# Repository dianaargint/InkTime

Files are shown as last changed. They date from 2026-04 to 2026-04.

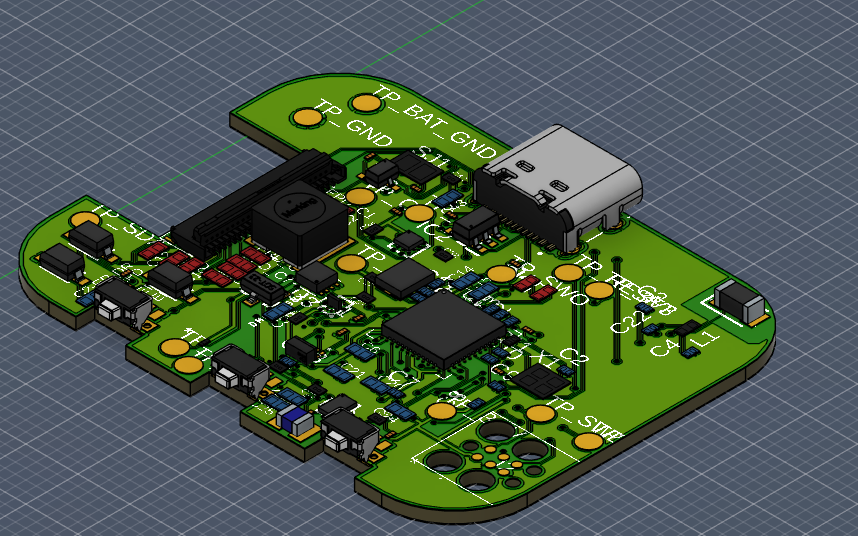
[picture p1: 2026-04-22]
Images/3d.png

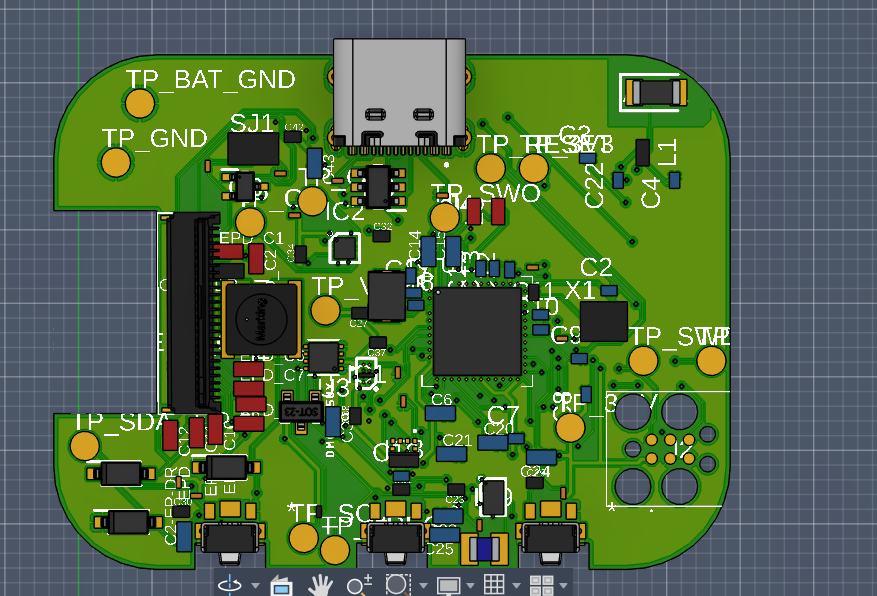
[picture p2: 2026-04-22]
Images/top3d.png

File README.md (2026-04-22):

# InkTime

InkTime este un smartwatch open-source cu consum redus, realizat in jurul microcontroller-ului **nRF52840**. Proiectul include un **display e-paper**, alimentare din **baterie Li-Po**, **incarcare prin USB-C**, **monitorizare baterie**, **IMU** si **feedback haptic**.

Scopul proiectului a fost realizarea unei placi compacte care sa poata fi integrata intr-o carcasa dedicata si sa poata functiona din baterie, cu un consum cat mai mic.

# Diagrama bloc

```text
+-------------+      +----------------+      +------------------+
| USB-C       |----->| ESD Protection |----->| BQ25180 Charger  |
+-------------+      +----------------+      +--------+---------+
                                                        |
                                                        v
                                                +---------------+
                                                | Li-Po Battery |
                                                +---+-------+---+
                                                    |       |
                                                    |       v
                                                    |   +-----------+
                                                    |   | MAX17048  |
                                                    |   | FuelGauge |
                                                    |   +-----------+
                                                    v
                                              +-------------+
                                              | RT6160 DC/DC|
                                              +------+------+ 
                                                     |
                                                     v
                                              +-------------+
                                              | nRF52840    |
                                              | BLE MCU     |
                                              +------+------+-------------------+
                                                     |      |         |         |
                                                     |      |         |         |
                                                     v      v         v         v
                                              +--------+ +------+ +-------+ +--------+
                                              | E-Paper| | IMU  | |Haptic | | Buttons|
                                              +--------+ +------+ +---+---+ +--------+
                                                                        |
                                                                        v
                                                                   +---------+
                                                                   | Shaker  |
                                                                   +---------+

```

## Bill of Materials (BOM)

| Component | Value / Part Number | Package | Qty | Description | Datasheet |
| --- | --- | --- | --- | --- | --- |
| MCU | NRF52840_QF | NORDIC_NRF_4_AQFN50P700X700X85_HS-74N | 1 | Main BLE microcontroller | [Datasheet](https://infocenter.nordicsemi.com/pdf/nRF52840_PS_v1.1.pdf) |
| PMIC charger | BQ25180YBGR | BQ25180YBGR_BGA8C40P2X4_100X155X50 | 1 | Li-Po charger | [Datasheet](https://www.ti.com/lit/ds/symlink/bq25180.pdf) |
| DC/DC | RT6160AWSC | RT6160AWSC_BGA15C40P3X5_140X230X60 | 1 | Buck-boost DC/DC converter | [Datasheet](https://www.richtek.com/assets/product_file/RT6160A/DS6160A-05.pdf) |
| Fuel gauge | MAX17048G+T10 | ESP32_C6_LIBRARY_SON50P200X200X80-9N | 1 | Battery fuel gauge | [Datasheet](https://www.analog.com/media/en/technical-documentation/data-sheets/max17048-max17049.pdf) |
| IMU | BMA421 | BMA423_BMA423 | 1 | Triaxial accelerometer | [Datasheet](https://www.bosch-sensortec.com/products/motion-sensors/accelerometers/bma421/) |
| Haptic driver | DRV2605YZFR | DRV2605YZFR_BGA9C50P3X3_144X144X62 | 1 | Haptic driver for vibration motor | [Datasheet](https://www.ti.com/lit/ds/symlink/drv2605.pdf) |
| USB ESD | USBLC6-2SC6Y | ESP32_C6_LIBRARY_3_SOT95P280X145-6N | 1 | USB ESD protection | [Datasheet](https://www.st.com/resource/en/datasheet/usblc6-2.pdf) |
| Antenna | 2450AT18B100E | 2450AT18B100E_ANTC3216X140N | 1 | 2.4 GHz chip antenna | [Datasheet](https://www.johansontechnology.com/datasheets/antennas/2450AT18B100.pdf) |
| Display connector | 503480-2400 | 503480-2400_5034802400 | 1 | FPC connector for e-paper display | [Datasheet](https://www.molex.com/en-us/products/part-detail/5034802400) |
| USB-C | KH-TYPE-C-16P | KH-TYPE-C-16P_KINGHELM_KH-TYPE-C-16P | 1 | USB-C connector | - |
| Debug connector | TC2030-IDC | TC2030-IDC_TC2030IDC | 1 | SWD programming / debug connector | [Datasheet](https://www.tag-connect.com/product/tc2030-idc) |
| EPD MOSFET | SI1308EDL-T1-GE3 | ESP32_C6_LIBRARY_6_SOT65P210X110-3N | 1 | MOSFET used in e-paper drive stage | [Datasheet](https://www.vishay.com/docs/68986/si1308edl.pdf) |
| EPD MOSFET | DMG2305UX-7 | ESP32_C6_LIBRARY_4_ESP32_WROVER_SPARKFUN-DISCRETESEMI_MOSFET | 1 | MOSFET used in e-paper drive stage | [Datasheet](https://www.diodes.com/assets/Datasheets/DMG2305UX.pdf) |
| Schottky diode | MBR0530 | ESP32_C6_LIBRARY_5_SOD3716X135N | 3 | Schottky diode used in EPD boost stage | [Datasheet](https://www.onsemi.com/pdf/datasheet/mbr0530t1-d.pdf) |
| Power inductor | FTC252012SR47MBCA | MLP2016SR47MT0S1_INDC2016X100N | 1 | Inductor for RT6160 converter | [JLC Part](https://jlcpcb.com/partdetail/6763488-FTC252012SR47MBCA/C5832368) |
| EPD inductor | 68uH | ESP32_C6_LIBRARY_2_IND_4828-WE-TPC_WRE | 1 | Inductor for e-paper boost stage | - |
| RF inductor | 3.9nH | NORDIC_NRF_2_RESC0402_L | 1 | RF matching network | - |
| RF inductor | 15nH | NORDIC_NRF_2_RESC0402_L | 1 | RF filter / matching | - |
| Power inductor | 10uH | NORDIC_NRF_2_RESC0402_L | 1 | Power stage passive | - |
| HF crystal | 32MHz | NORDIC_NRF_BT-XTAL_2016_N | 1 | Main MCU clock | - |
| LF crystal | 32.768kHz | NORDIC_NRF_1_XTAL_3215_N | 1 | RTC / low-power clock | - |
| Buttons | EVP-AKE31A | 2025-10-22_07-23-44_LIBRARY_SW_EVP-AKE31A_PAN | 3 | Tactile user buttons | - |
| Solder jumper | SJ | ESP32_C6_LIBRARY_7_JUMPER_SJ | 1 | Configuration jumper | - |
| Test pads | HECTOR_WATCH_1_TPTP20R | HECTOR_WATCH_1_TP20R | 14 | Test points for debug / power / signals | - |

BOM-ul complet generat automat se gaseste in folderul Manufacturing.

## Pinii folositi de nRF52840

| Pin nRF52840 | Semnal | Componenta / destinatie | Rol |
| --- | --- | --- | --- |
| P0.00 / XL1 | XL1 | Cristal 32.768kHz | clock low-power / RTC |
| P0.01 / XL2 | XL2 | Cristal 32.768kHz | clock low-power / RTC |
| P0.02 | SCK | Display e-paper | SPI clock pentru display |
| P0.03 | MOSI | Display e-paper | SPI data pentru display |
| P0.05 | EPD_CS | Display e-paper | chip select pentru display |
| P0.06 | SDA | BMA421 / DRV2605 / MAX17048 / BQ25180 / RT6160 | magistrala I2C comuna |
| P0.07 | SCL | BMA421 / DRV2605 / MAX17048 / BQ25180 / RT6160 | magistrala I2C comuna |
| P0.08 | IMU_INT1 | BMA421 | interrupt de la IMU |
| P0.10 | ALERT | MAX17048 | alerta fuel gauge |
| P0.11 | PMIC_INT | BQ25180YBGR | interrupt de la charger |
| P0.12 | HAPTIC_EN | DRV2605YZFR | enable pentru driverul haptic |
| P0.13 | SW_UP | Buton UP | input utilizator |
| P0.14 | SW_ENT | Buton ENTER | input utilizator |
| P0.15 | EPD_DC | Display e-paper | selectare data / command |
| P0.16 | EPD_RST | Display e-paper | reset display |
| P0.17 | EPD_BUSY | Display e-paper | busy status de la display |
| P0.18 / RESET | RESET | Sistem | reset hardware |
| P1.00 | SWO | Debug | trace output |
| P1.02 | SW_DN | Buton DOWN | input utilizator |
| P1.08 | IMU_INT2 | BMA421 | al doilea interrupt de la IMU |
| SWDIO | SWDIO | TC2030-IDC | programare / debug |
| SWDCLK | SWDCLK | TC2030-IDC | programare / debug |
| ANT | RF | Antena 2.4 GHz | transmisie BLE |
| VBUS | VBUS | USB-C | alimentare 5V |

Am ales pinii in asa fel incat sa separ cat mai clar liniile de comunicatie de semnalele de control. Display-ul foloseste SPI pentru transferul de date, iar semnalele EPD_CS, EPD_DC, EPD_RST si EPD_BUSY sunt separate pentru controlul corect al panoului. IMU-ul, fuel gauge-ul, charger-ul, convertorul DC/DC si driverul haptic folosesc aceeasi magistrala I2C, ceea ce reduce numarul de pini ocupati. Butoanele sunt puse pe GPIO-uri dedicate, iar liniile SWDIO, SWDCLK si SWO sunt folosite pentru programare si debugging.

## Descriere hardware
1. Microcontroller

Microcontroller-ul principal al proiectului este nRF52840 (U1). Acesta este componenta centrala a sistemului si se ocupa de:

comunicatia BLE, controlul display-ului e-paper, comunicatia cu senzorii si circuitele de power prin I2C, citirea butoanelor, controlul driverului haptic, interfata de debug SWD

Pentru clock sunt folosite doua cristale:

X1 = 32MHz
X2 = 32.768kHz

Cristalul de 32MHz este folosit pentru functionarea principala a MCU-ului si pentru partea de radio, iar cristalul de 32.768kHz este folosit pentru RTC si modurile low-power.

2. Alimentare si management energetic

Partea de alimentare am impartit-o in trei blocuri principale:

BQ25180YBGR

IC1 = BQ25180YBGR se ocupa de incarcarea bateriei Li-Po din USB-C. Intrarea de 5V vine din VBUS, iar iesirea merge spre baterie. Circuitul are si semnal de interrupt catre MCU pentru monitorizarea starii de incarcare.

MAX17048

U3 = MAX17048G+T10 monitorizeaza tensiunea bateriei si comunica prin I2C cu nRF52840. Are si semnal de alerta catre MCU pentru praguri critice sau schimbari de stare.

RT6160AWSC

IC9 = RT6160AWSC este convertorul buck-boost care genereaza alimentarea stabila 3V3 / VREG pentru sistem. Acesta este necesar deoarece tensiunea bateriei variaza in functie de starea de incarcare, iar sistemul are nevoie de o alimentare stabila.

3. Bateria

Am folosit o baterie de tip LP502030, 3.7V, aproximativ 250mAh. In proiect, bateria nu este conectata prin conector JST, ci direct la doua test pad-uri:

TP_VBAT, TP_BAT_GND

Am ales varianta asta ca sa economisesc spatiu si pentru ca asta era si cerinta proiectului.

4. Display e-paper

Display-ul este conectat prin conectorul 503480-2400 si este controlat prin:

SCK, MOSI, EPD_CS,EPD_DC, EPD_RST, EPD_BUSY

5. IMU

IMU-ul folosit este BMA421 (IC3) si comunica prin I2C. Are doua semnale de interrupt:

IMU_INT1
,IMU_INT2

Aceste semnale sunt conectate la MCU pentru detectarea rapida a evenimentelor de miscare si pentru trezirea sistemului din moduri low-power.

6. Haptic

Pentru feedback haptic este folosit DRV2605YZFR (IC2), care comanda motorul de vibratie. Comunicarea este facuta pe I2C, iar activarea poate fi controlata si printr-un semnal GPIO dedicat.

7. USB-C si protectie ESD

Conectorul J4 = KH-TYPE-C-16P este folosit pentru alimentare si optional pentru interfata USB. Protectia ESD este facuta cu USBLC6-2SC6Y, pentru a proteja liniile sensibile la descarcari electrostatice.

8. RF si antena

Antena este ANT1 = 2450AT18B100E si este conectata la pinul RF al nRF52840 printr-o retea de matching. Antena este pusa la marginea placii, iar sub ea am lasat zona fara plan de masa si fara trasee, conform regulilor de proiectare RF.

## PCB si layout
Board specifications
- dimensiunea placii: 46 mm x 35 mm
- grosimea PCB-ului: 1 mm
- componentele sunt plasate pe TOP
- rutarea este facuta pe Top si Bottom
- exista poligoane de GND pe Top si Bottom
  
Routing rules

- traseele de semnal au fost rutate cu minimum 0.15 mm
- traseele de putere au fost rutate cu 0.3 mm acolo unde spatiul a permis
- in zonele foarte dense, unele segmente scurte au trebuit ingustate local
  
Ground planes

Am folosit planuri de masa pe placa, iar in zonele importante am pus si via stitching, mai ales in jurul zonei RF si al microcontroller-ului.

Antena si keepout

Antena este pusa la marginea PCB-ului, iar sub ea:

- nu exista plan de masa
- nu exista trasee
- nu exista turnare de cupru

Acest lucru a fost facut pentru a nu afecta performanta RF.
Pe parcursul proiectarii au aparut mai multe probleme, mai ales in zonele cu densitate mare de componente:

- zona din jurul nRF52840 a fost dificil de rutat
- integrarea bateriei, display-ului si shaker-ului in acelasi volum a fost dificila

## Integrare mecanica si 3D

In modelul 3D au fost incluse:
- PCB-ul
- carcasa
- bateria
- display-ul
- shaker-ul

Au fost verificate:
- alinierea USB-C
- alinierea butoanelor
- pozitia display-ului fata de carcasa
- spatiul pentru baterie si shaker

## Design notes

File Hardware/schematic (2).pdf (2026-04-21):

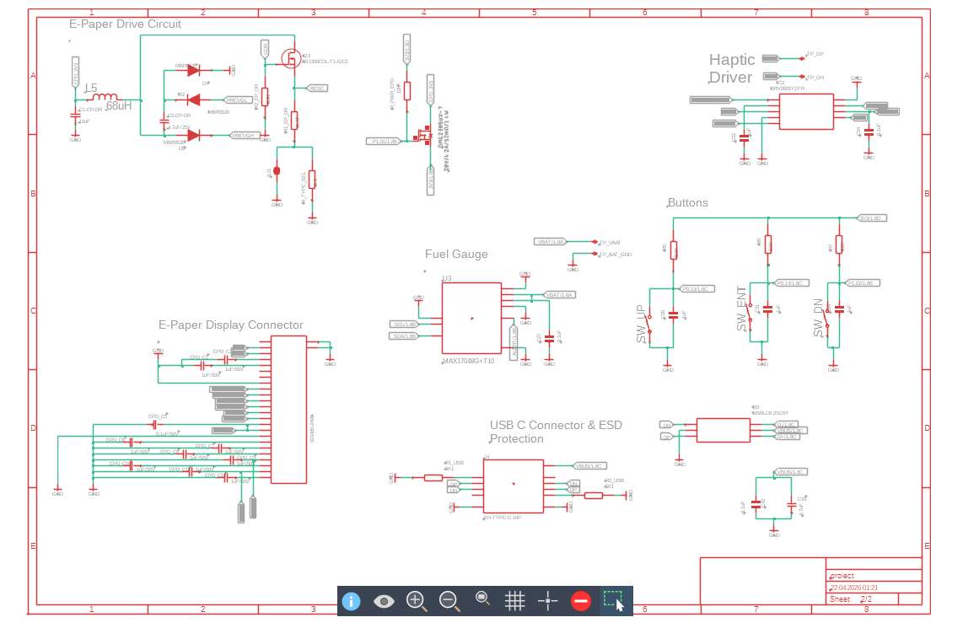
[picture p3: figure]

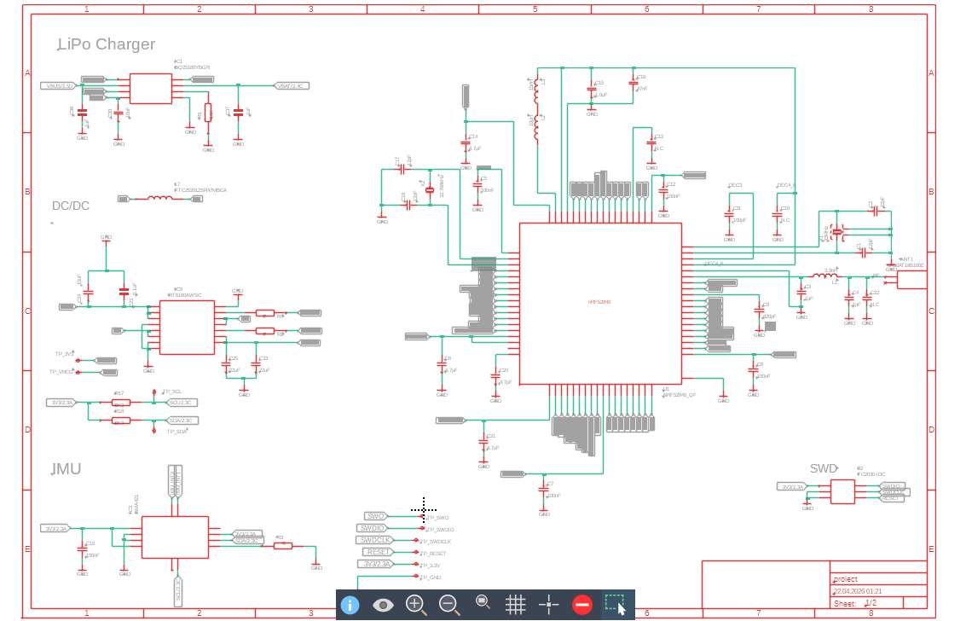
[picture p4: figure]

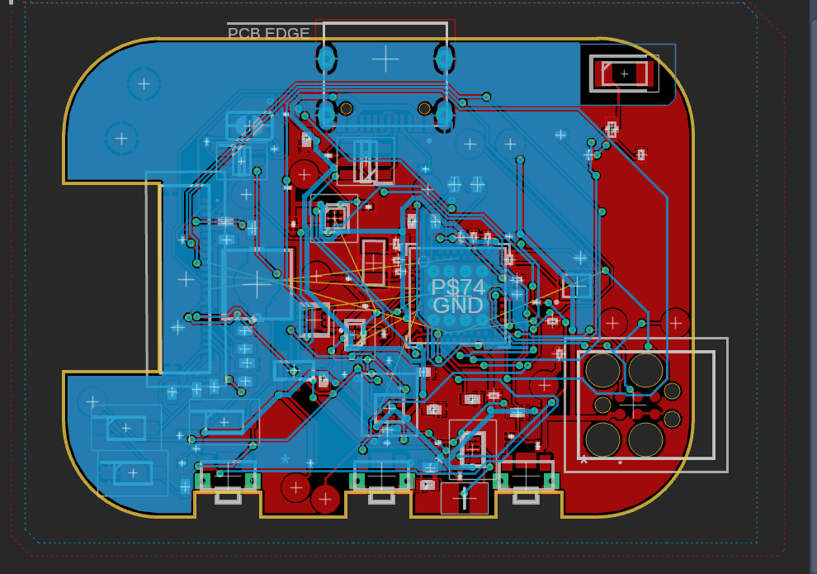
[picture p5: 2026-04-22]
Images/bottom2d.png

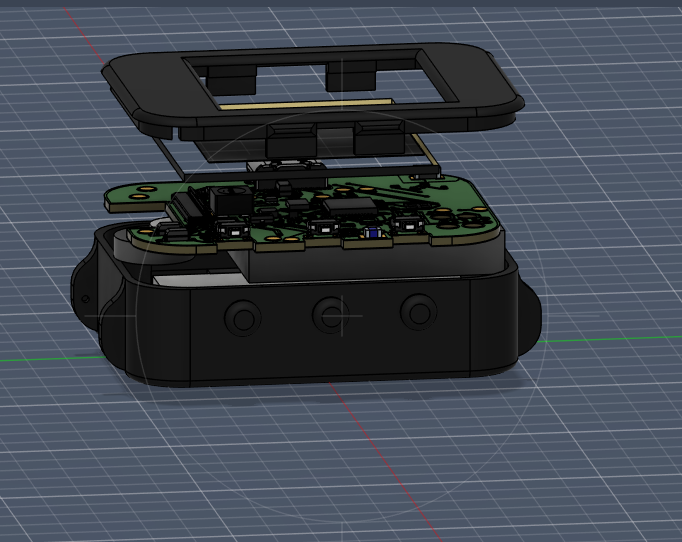
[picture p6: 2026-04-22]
Images/explodedview.png

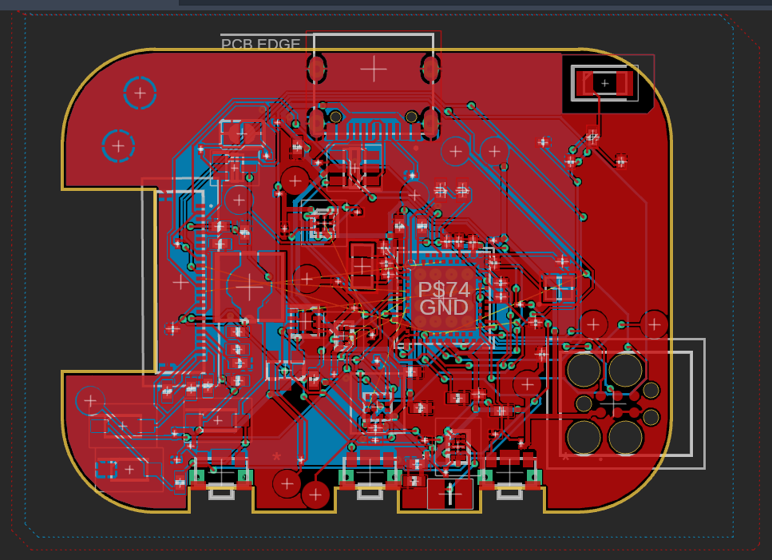
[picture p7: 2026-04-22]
Images/top2d.png

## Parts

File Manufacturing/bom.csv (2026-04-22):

Qty | Value | Device | Package
1 |  | ESP32_C6_LIBRARY_7_JUMPER_SJ | ESP32_C6_LIBRARY_7_JUMPER_SJ
3 | 0 | CPF0201D7K68C1_CPF0201D7K68C1 | CPF0201D7K68C1_0201
4 | 0.1uF | GRM011R60J152KE01L_2_GRM011R60J152KE01L | GRM011R60J152KE01L_2_CAPC0201X13N
1 | 0.1uF/50V | NORDIC_NRF_3_CAPACITOR_0201_L | NORDIC_NRF_3_RESC0201_L
1 | 0.47 | CPF0201D7K68C1_CPF0201D7K68C1 | CPF0201D7K68C1_0201
1 | 1.0µF | PERFECT_0402_CAP_0402 | PERFECT_0402_0402
5 | 100nF | NORDIC_NRF_3_CAPACITOR_0201_L | NORDIC_NRF_3_RESC0201_L
1 | 100pF | NORDIC_NRF_3_CAPACITOR_0201_L | NORDIC_NRF_3_RESC0201_L
6 | 10K | CPF0201D7K68C1_CPF0201D7K68C1 | CPF0201D7K68C1_0201
3 | 10uF | PERFECT_0402_CAP_0402 | PERFECT_0402_0402
1 | 10µH | NORDIC_NRF_2_INDUCTOR_0402_L | NORDIC_NRF_2_RESC0402_L
4 | 12pF | NORDIC_NRF_3_CAPACITOR_0201_L | NORDIC_NRF_3_RESC0201_L
1 | 15nH | NORDIC_NRF_2_INDUCTOR_0402_L | NORDIC_NRF_2_RESC0402_L
2 | 1pF | NORDIC_NRF_3_CAPACITOR_0201_L | NORDIC_NRF_3_RESC0201_L
6 | 1uF | GRM011R60J152KE01L_2_GRM011R60J152KE01L | GRM011R60J152KE01L_2_CAPC0201X13N
9 | 1uF/50V | PERFECT_0402_CAP_0402 | PERFECT_0402_0402
1 | 02.feb | CPF0201D7K68C1_CPF0201D7K68C1 | CPF0201D7K68C1_0201
3 | 2025-10-22_07-23-44_LIBRARY_EVP-AKE31ASW_EVP-AKE31A_PAN | 2025-10-22_07-23-44_LIBRARY_EVP-AKE31ASW_EVP-AKE31A_PAN | 2025-10-22_07-23-44_LIBRARY_SW_EVP-AKE31A_PAN
1 | 20V/4.2A/52m?/1.4W | ESP32_C6_LIBRARY_4_ESP32_WROVER_SPARKFUN-DISCRETESEMI_MOSFET_PCH-DMG2305UX-7 | ESP32_C6_LIBRARY_4_ESP32_C6_LIBRARY_4_ESP32_C6_LIBRARY_4_ESP32_C6_LIBRARY_4_ESP32_WROVER_SPARKFUN-DISCRETESEMI_SOT23-3
2 | 22uF | PERFECT_0402_CAP_0402 | PERFECT_0402_0402
1 | 2450AT18B100E | 2450AT18B100E_2450AT18B100E | 2450AT18B100E_ANTC3216X140N
1 | 3.9nH | NORDIC_NRF_2_INDUCTOR_0402_L | NORDIC_NRF_2_RESC0402_L
1 | 32.768kHz | NORDIC_NRF_1_XTAL_32KHZ | NORDIC_NRF_1_XTAL_3215_N
1 | 32MHz | NORDIC_NRF_XTAL_32MHZ | NORDIC_NRF_BT-XTAL_2016_N
2 | 3K3 | CPF0201D7K68C1_CPF0201D7K68C1 | CPF0201D7K68C1_0201
1 | 4.7uF | PERFECT_0402_CAP_0402 | PERFECT_0402_0402
1 | 4.7uF/25V | PERFECT_0402_CAP_0402 | PERFECT_0402_0402
4 | 4.7µF | PERFECT_0402_CAP_0402 | PERFECT_0402_0402
1 | 47nF | NORDIC_NRF_3_CAPACITOR_0201_L | NORDIC_NRF_3_RESC0201_L
1 | 503480-2400_503480-2400 | 503480-2400_503480-2400 | 503480-2400_5034802400
2 | 5K1 | CPF0201D7K68C1_CPF0201D7K68C1 | CPF0201D7K68C1_0201
1 | 68uH | ESP32_C6_LIBRARY_2_744043680IND_4828-WE-TPC_WRE | ESP32_C6_LIBRARY_2_IND_4828-WE-TPC_WRE
1 | 820pF | NORDIC_NRF_3_CAPACITOR_0201_L | NORDIC_NRF_3_RESC0201_L
1 | BMA421 | BMA423_BMA423 | BMA423_BMA423
1 | BQ25180YBGR | BQ25180YBGR_BQ25180YBGR | BQ25180YBGR_BGA8C40P2X4_100X155X50
1 | DRV2605YZFR | DRV2605YZFR_DRV2605YZFR | DRV2605YZFR_BGA9C50P3X3_144X144X62
1 | FTC252012SR47MBCA | MLP2016SR47MT0S1_FTC252012SR47MBCA | MLP2016SR47MT0S1_INDC2016X100N
14 | HECTOR_WATCH_1_TPTP20R | HECTOR_WATCH_1_TPTP20R | HECTOR_WATCH_1_TP20R
1 | KH-TYPE-C-16P | KH-TYPE-C-16P_KH-TYPE-C-16P | KH-TYPE-C-16P_KINGHELM_KH-TYPE-C-16P | https://www.snapeda.com/parts/KH-TYPE-C-16P/Kinghelm/view-part/?ref=snap
1 | MAX17048G+T10 | ESP32_C6_LIBRARY_MAX17048G+T10 | ESP32_C6_LIBRARY_SON50P200X200X80-9N
3 | MBR0530 | ESP32_C6_LIBRARY_5_MBR0530 | ESP32_C6_LIBRARY_5_SOD3716X135N
3 | N.C | NORDIC_NRF_3_CAPACITOR_0201_L | NORDIC_NRF_3_RESC0201_L
1 | NRF52840_QF | NORDIC_NRF_4_NRF52840_QF | NORDIC_NRF_4_AQFN50P700X700X85_HS-74N
1 | RT6160AWSC | RT6160AWSC_RT6160AWSC | RT6160AWSC_BGA15C40P3X5_140X230X60
1 | SI1308EDL-T1-GE3 | ESP32_C6_LIBRARY_6_SI1308EDL-T1-GE3 | ESP32_C6_LIBRARY_6_SOT65P210X110-3N
1 | TC2030-IDC | TC2030-IDC_TC2030-IDC | TC2030-IDC_TC2030IDC
1 | USBLC6-2SC6Y | ESP32_C6_LIBRARY_3_USBLC6-2SC6Y | ESP32_C6_LIBRARY_3_SOT95P280X145-6N

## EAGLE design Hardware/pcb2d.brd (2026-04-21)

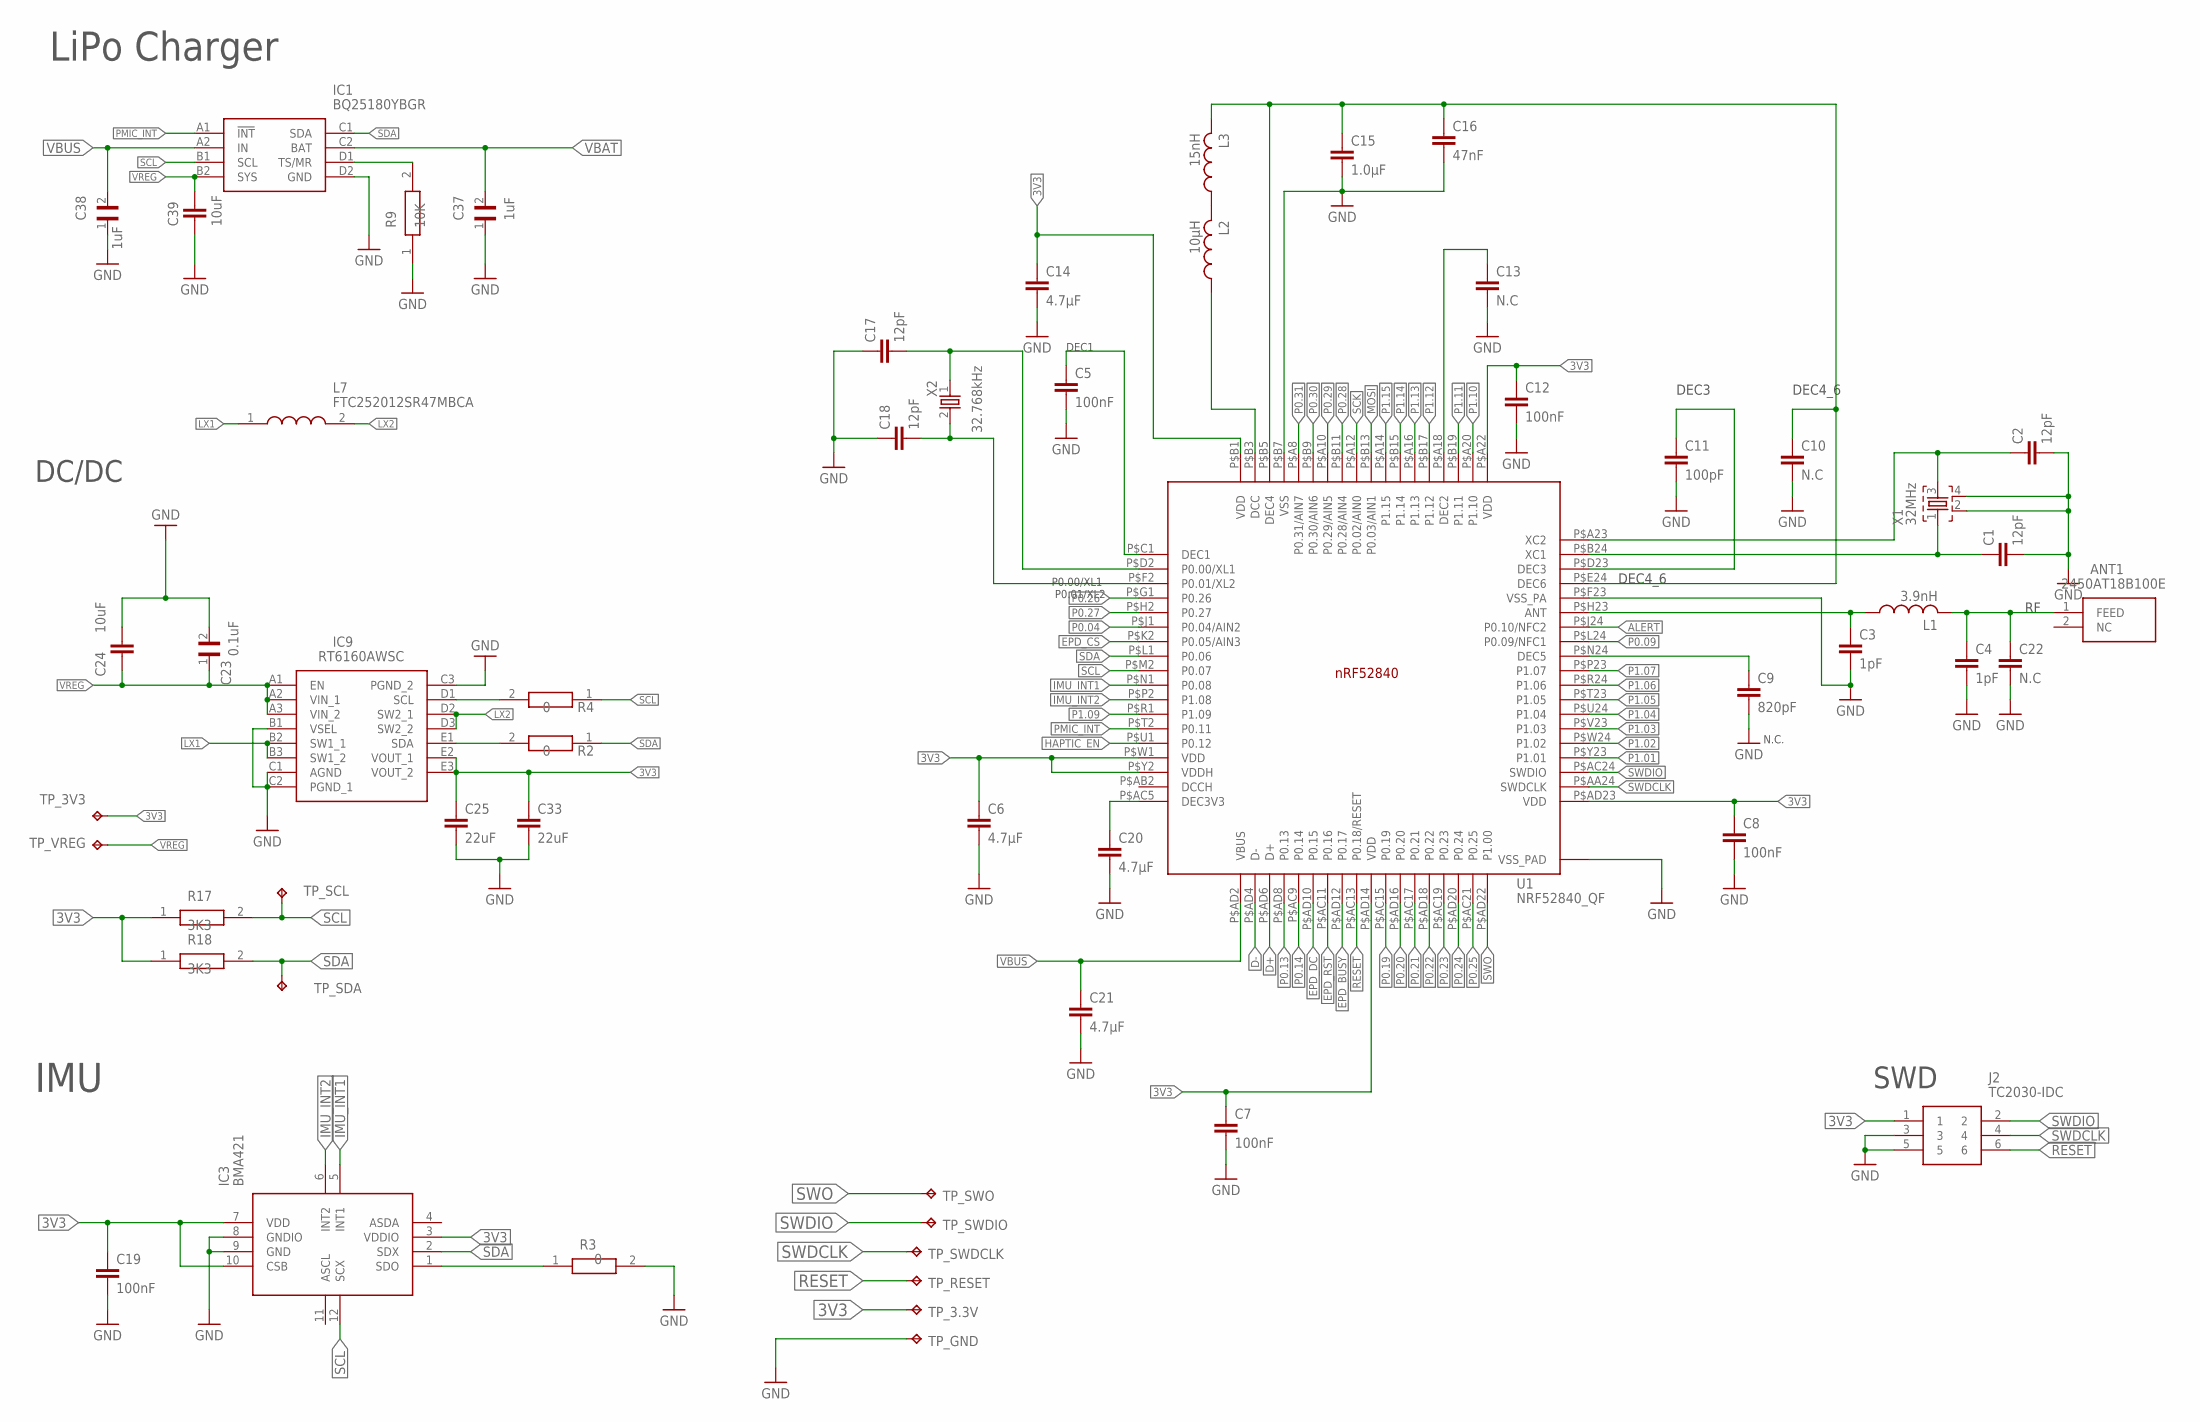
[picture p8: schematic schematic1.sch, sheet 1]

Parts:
ANT1: 2450AT18B100E; 2450AT18B100E_ANTC3216X140N
C1, C2, C17, C18: 12pF; NORDIC_NRF_3_RESC0201_L
C3, C4: 1pF; NORDIC_NRF_3_RESC0201_L
C5, C7, C8, C12, C19: 100nF; NORDIC_NRF_3_RESC0201_L
C6, C14, C20, C21: 4.7µF; PERFECT_0402_0402
C9: 820pF; NORDIC_NRF_3_RESC0201_L
C10, C13, C22: N.C; NORDIC_NRF_3_RESC0201_L
C11: 100pF; NORDIC_NRF_3_RESC0201_L
C15: 1.0µF; PERFECT_0402_0402
C16: 47nF; NORDIC_NRF_3_RESC0201_L
C23: 0.1uF; GRM011R60J152KE01L_2_CAPC0201X13N
C24, C39: 10uF; PERFECT_0402_0402
C25, C33: 22uF; PERFECT_0402_0402
C37, C38: 1uF; GRM011R60J152KE01L_2_CAPC0201X13N
IC1: BQ25180YBGR; BQ25180YBGR_BGA8C40P2X4_100X155X50
IC3: BMA421; BMA423_BMA423
IC9: RT6160AWSC; RT6160AWSC_BGA15C40P3X5_140X230X60
J2: TC2030-IDC; TC2030-IDC_TC2030IDC
L1: 3.9nH; NORDIC_NRF_2_RESC0402_L
L2: 10µH; NORDIC_NRF_2_RESC0402_L
L3: 15nH; NORDIC_NRF_2_RESC0402_L
L7: FTC252012SR47MBCA; MLP2016SR47MT0S1_INDC2016X100N
R2, R3, R4: 0; CPF0201D7K68C1_0201
R9: 10K; CPF0201D7K68C1_0201
R17, R18: 3K3; CPF0201D7K68C1_0201
TP_3.3V, TP_3V3: HECTOR_WATCH_1_TPTP20R; HECTOR_WATCH_1_TP20R
TP_GND: HECTOR_WATCH_1_TPTP20R; HECTOR_WATCH_1_TP20R
TP_RESET: HECTOR_WATCH_1_TPTP20R; HECTOR_WATCH_1_TP20R
TP_SCL: HECTOR_WATCH_1_TPTP20R; HECTOR_WATCH_1_TP20R
TP_SDA: HECTOR_WATCH_1_TPTP20R; HECTOR_WATCH_1_TP20R
TP_SWDCLK: HECTOR_WATCH_1_TPTP20R; HECTOR_WATCH_1_TP20R
TP_SWDIO: HECTOR_WATCH_1_TPTP20R; HECTOR_WATCH_1_TP20R
TP_SWO: HECTOR_WATCH_1_TPTP20R; HECTOR_WATCH_1_TP20R
TP_VREG: HECTOR_WATCH_1_TPTP20R; HECTOR_WATCH_1_TP20R
U1: NRF52840_QF; NORDIC_NRF_4_AQFN50P700X700X85_HS-74N
X1: 32MHz; NORDIC_NRF_BT-XTAL_2016_N
X2: 32.768kHz; NORDIC_NRF_1_XTAL_3215_N

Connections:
3V3: C6.1, C7.1, C8.1, C12.1, C14.1, C19.1, C25.1, C33.1, IC3.3 (VDDIO), IC3.7 (VDD), IC3.10 (CSB), IC9.E2 (VOUT_1), IC9.E3 (VOUT_2), J2.1, R17.1, R18.1, TP_3.3V.TP, TP_3V3.TP, U1.P$A22 (VDD), U1.P$AD14 (VDD), U1.P$AD23 (VDD), U1.P$B1 (VDD), U1.P$W1 (VDD), U1.P$Y2 (VDDH); also elsewhere on the board
ALERT: U1.P$J24 (P0.10/NFC2); also elsewhere on the board
D+: U1.P$AD6 (D+); also elsewhere on the board
D-: U1.P$AD4 (D-); also elsewhere on the board
EPD_BUSY: U1.P$AD12 (P0.17); also elsewhere on the board
EPD_CS: U1.P$K2 (P0.05/AIN3); also elsewhere on the board
EPD_DC: U1.P$AD10 (P0.15); also elsewhere on the board
EPD_RST: U1.P$AC11 (P0.16); also elsewhere on the board
GND: C1.2, C2.2, C3.2, C4.2, C5.2, C6.2, C7.2, C8.2, C9.2, C10.2, C11.2, C12.2, C13.2, C14.2, C15.2, C16.2, C17.1, C18.1, C19.2, C20.2, C21.2, C22.2, C23.2, C24.1, C25.2, C33.2, C37.1, C38.1, C39.2, IC1.D2 (GND), IC3.8 (GNDIO), IC3.9 (GND), IC9.B1 (VSEL), IC9.C1 (AGND), IC9.C2 (PGND_1), IC9.C3 (PGND_2), J2.3, J2.5, R3.2, R9.1, TP_GND.TP, U1.P$74 (VSS_PAD), U1.P$75 (VSS_PAD), U1.P$76 (VSS_PAD), U1.P$77 (VSS_PAD), U1.P$78 (VSS_PAD), U1.P$79 (VSS_PAD), U1.P$80 (VSS_PAD), U1.P$81 (VSS_PAD), U1.P$82 (VSS_PAD), U1.P$83 (VSS_PAD), U1.P$84 (VSS_PAD), U1.P$85 (VSS_PAD), U1.P$86 (VSS_PAD), U1.P$87 (VSS_PAD), U1.P$88 (VSS_PAD), U1.P$89 (VSS_PAD), U1.P$90 (VSS_PAD), U1.P$B7 (VSS), U1.P$F23 (VSS_PA), X1.2, X1.4; also elsewhere on the board
HAPTIC_EN: U1.P$U1 (P0.12); also elsewhere on the board
IMU_INT1: IC3.5 (INT1), U1.P$N1 (P0.08)
IMU_INT2: IC3.6 (INT2), U1.P$P2 (P1.08)
LX1: IC9.B2 (SW1_1), IC9.B3 (SW1_2), L7.1
LX2: IC9.D2 (SW2_1), IC9.D3 (SW2_2), L7.2
MOSI: U1.P$B13 (P0.03/AIN1); also elsewhere on the board
unnamed: C3.1, L1.1, U1.P$H23 (ANT)
unnamed: IC9.D1 (SCL), R4.2
unnamed: IC1.D1 (TS/MR), R9.2
unnamed: C9.1, U1.P$N24 (DEC5)
unnamed: IC9.E1 (SDA), R2.2
unnamed: ANT1.1 (FEED), C4.1, C22.1, L1.2
unnamed: C11.1, U1.P$D23 (DEC3)
unnamed: IC3.1 (SDO), R3.1
unnamed: L2.2, L3.1
unnamed: C20.1, U1.P$AC5 (DEC3V3)
unnamed: C5.1, U1.P$C1 (DEC1)
unnamed: C17.2, U1.P$D2 (P0.00/XL1), X2.1
unnamed: C18.2, U1.P$F2 (P0.01/XL2), X2.2
unnamed: C1.1, U1.P$B24 (XC1), X1.1
unnamed: C2.1, U1.P$A23 (XC2), X1.3
unnamed: C10.1, C15.1, C16.1, L3.2, U1.P$B5 (DEC4), U1.P$E24 (DEC6)
unnamed: C13.1, U1.P$A18 (DEC2)
unnamed: L2.1, U1.P$B3 (DCC)
P0.04: U1.P$J1 (P0.04/AIN2)
P0.09: U1.P$L24 (P0.09/NFC1)
P0.13: U1.P$AD8 (P0.13); also elsewhere on the board
P0.14: U1.P$AC9 (P0.14); also elsewhere on the board
P0.19: U1.P$AC15 (P0.19)
P0.20: U1.P$AD16 (P0.20)
P0.21: U1.P$AC17 (P0.21)
P0.22: U1.P$AD18 (P0.22)
P0.23: U1.P$AC19 (P0.23)
P0.24: U1.P$AD20 (P0.24)
P0.25: U1.P$AC21 (P0.25)
P0.26: U1.P$G1 (P0.26)
P0.27: U1.P$H2 (P0.27)
P0.28: U1.P$B11 (P0.28/AIN4)
P0.29: U1.P$A10 (P0.29/AIN5)
P0.30: U1.P$B9 (P0.30/AIN6)
P0.31: U1.P$A8 (P0.31/AIN7)
P1.01: U1.P$Y23 (P1.01); also elsewhere on the board
P1.02: U1.P$W24 (P1.02); also elsewhere on the board
P1.03: U1.P$V23 (P1.03)
P1.04: U1.P$U24 (P1.04)
P1.05: U1.P$T23 (P1.05)
P1.06: U1.P$R24 (P1.06)
P1.07: U1.P$P23 (P1.07)
P1.09: U1.P$R1 (P1.09)
P1.10: U1.P$A20 (P1.10)
P1.11: U1.P$B19 (P1.11)
P1.12: U1.P$B17 (P1.12)
P1.13: U1.P$A16 (P1.13)
P1.14: U1.P$B15 (P1.14)
P1.15: U1.P$A14 (P1.15)
PMIC_INT: IC1.A1 (!INT), U1.P$T2 (P0.11)
RESET: J2.6, TP_RESET.TP, U1.P$AC13 (P0.18/RESET)
SCK: U1.P$A12 (P0.02/AIN0); also elsewhere on the board
SCL: IC1.B1 (SCL), IC3.12 (SCX), R4.1, R17.2, TP_SCL.TP, U1.P$M2 (P0.07); also elsewhere on the board
SDA: IC1.C1 (SDA), IC3.2 (SDX), R2.1, R18.2, TP_SDA.TP, U1.P$L1 (P0.06); also elsewhere on the board
SWDCLK: J2.4, TP_SWDCLK.TP, U1.P$AA24 (SWDCLK)
SWDIO: J2.2, TP_SWDIO.TP, U1.P$AC24 (SWDIO)
SWO: TP_SWO.TP, U1.P$AD22 (P1.00)
VBAT: C37.2, IC1.C2 (BAT); also elsewhere on the board
VBUS: C21.1, C38.2, IC1.A2 (IN), U1.P$AD2 (VBUS); also elsewhere on the board
VREG: C23.1, C24.2, C39.1, IC1.B2 (SYS), IC9.A1 (EN), IC9.A2 (VIN_1), IC9.A3 (VIN_2), TP_VREG.TP

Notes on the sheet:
SWD
LiPo Charger
IMU
DC/DC
N.C.
DEC1
P0.00/XL1 P0.01/XL2
DEC3
DEC4_6

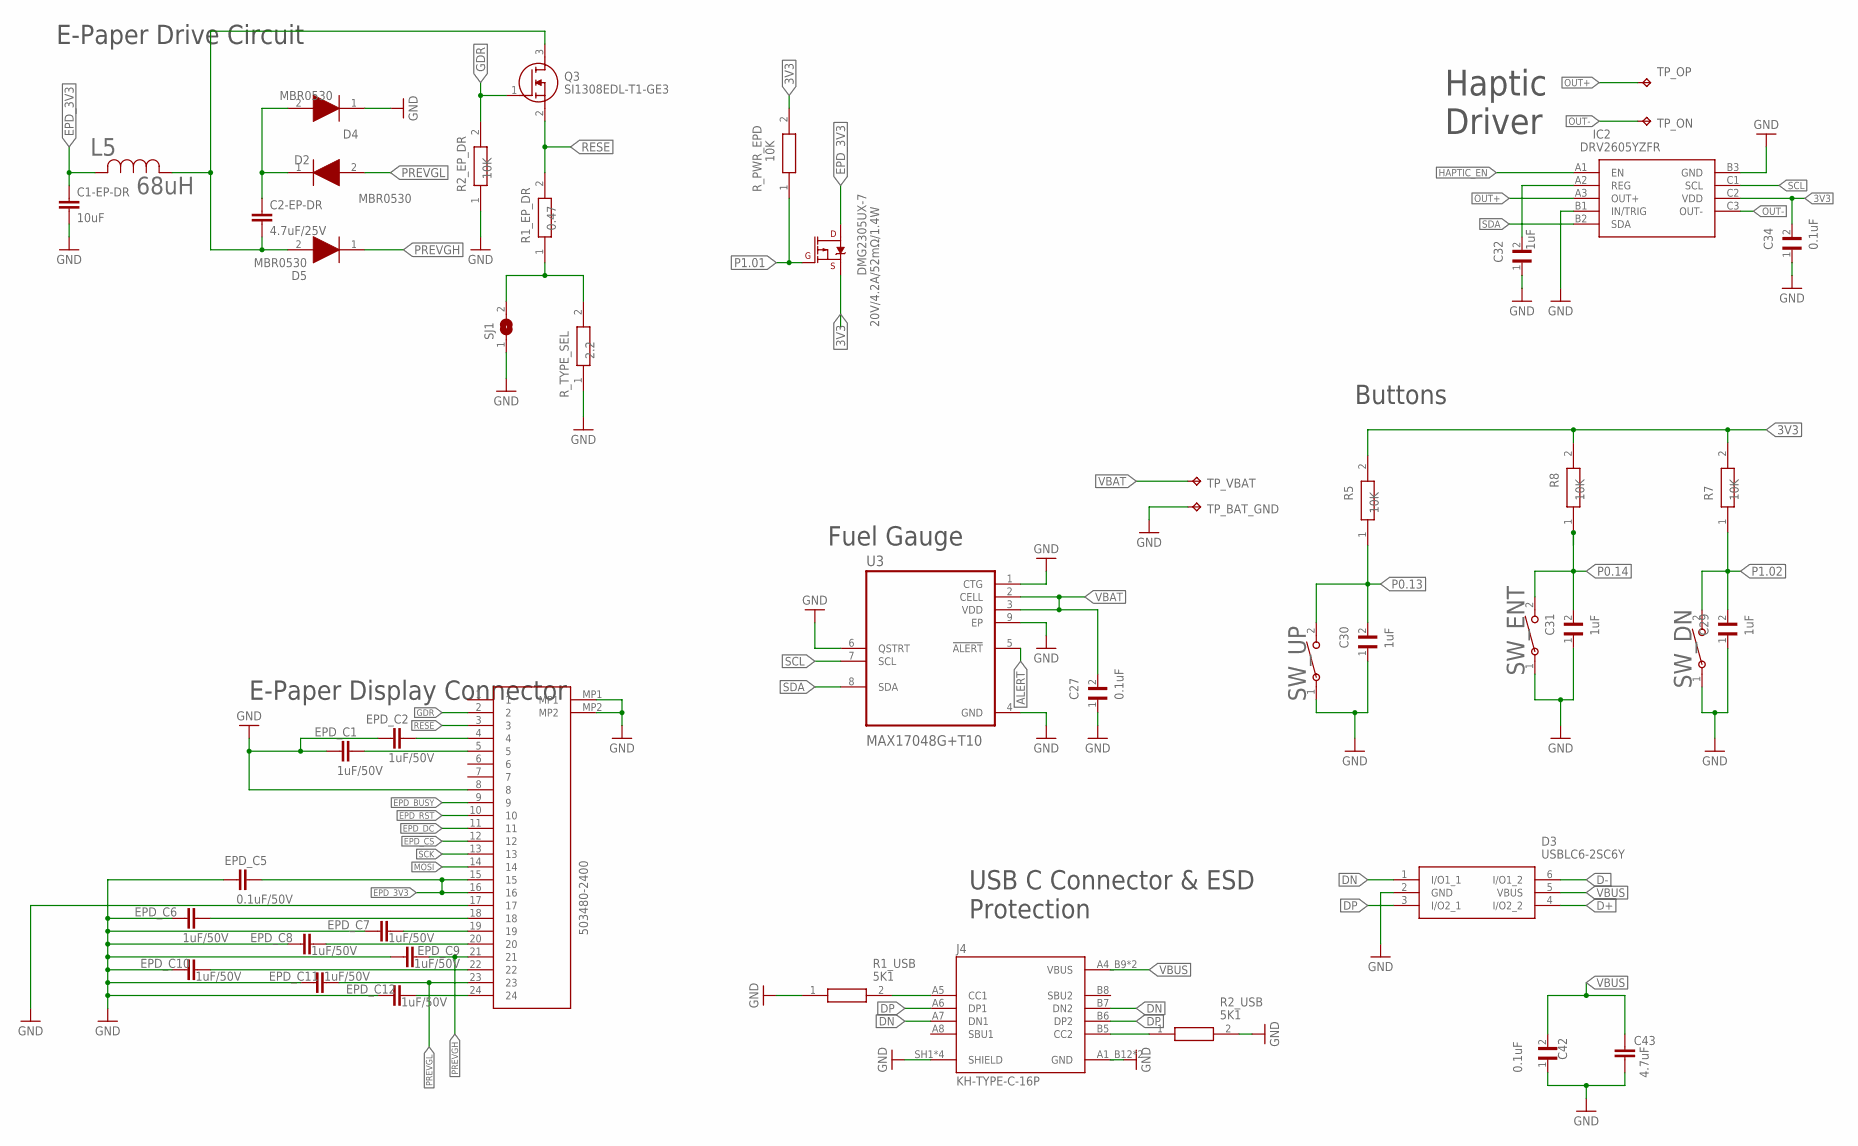
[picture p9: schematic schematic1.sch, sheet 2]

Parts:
503480-2400: 503480-2400_503480-2400; 503480-2400_5034802400
C1-EP-DR: 10uF; PERFECT_0402_0402
C2-EP-DR: 4.7uF/25V; PERFECT_0402_0402
C27, C34, C42: 0.1uF; GRM011R60J152KE01L_2_CAPC0201X13N
C29, C30, C31, C32: 1uF; GRM011R60J152KE01L_2_CAPC0201X13N
C43: 4.7uF; PERFECT_0402_0402
D2, D4, D5: MBR0530; ESP32_C6_LIBRARY_5_SOD3716X135N
D3: USBLC6-2SC6Y; ESP32_C6_LIBRARY_3_SOT95P280X145-6N
DMG2305UX-7: 20V/4.2A/52mΩ/1.4W; ESP32_C6_LIBRARY_4_ESP32_C6_LIBRARY_4_ESP32_C6_LIBRARY_4_ES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
EPD_C1, EPD_C2, EPD_C6, EPD_C7, EPD_C8, EPD_C9, EPD_C10, EPD_C11, EPD_C12: 1uF/50V; PERFECT_0402_0402
EPD_C5: 0.1uF/50V; NORDIC_NRF_3_RESC0201_L
IC2: DRV2605YZFR; DRV2605YZFR_BGA9C50P3X3_144X144X62
J4: KH-TYPE-C-16P; KH-TYPE-C-16P_KINGHELM_KH-TYPE-C-16P
L5: 68uH; ESP32_C6_LIBRARY_2_IND_4828-WE-TPC_WRE
Q3: SI1308EDL-T1-GE3; ESP32_C6_LIBRARY_6_SOT65P210X110-3N
R1_EP_DR: 0.47; CPF0201D7K68C1_0201
R1_USB, R2_USB: 5K1; CPF0201D7K68C1_0201
R2_EP_DR, R5, R7, R8: 10K; CPF0201D7K68C1_0201
R_PWR_EPD: 10K; CPF0201D7K68C1_0201
R_TYPE_SEL: 2.2; CPF0201D7K68C1_0201
SJ1: ESP32_C6_LIBRARY_7_JUMPER_SJ
SW_DN: 2025-10-22_07-23-44_LIBRARY_EVP-AKE31ASW_EVP-AKE3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; 2025-10-22_07-23-44_LIBRARY_SW_EVP-AKE31A_PAN
SW_ENT: 2025-10-22_07-23-44_LIBRARY_EVP-AKE31ASW_EVP-AKE3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; 2025-10-22_07-23-44_LIBRARY_SW_EVP-AKE31A_PAN
SW_UP: 2025-10-22_07-23-44_LIBRARY_EVP-AKE31ASW_EVP-AKE3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; 2025-10-22_07-23-44_LIBRARY_SW_EVP-AKE31A_PAN
TP_BAT_GND: HECTOR_WATCH_1_TPTP20R; HECTOR_WATCH_1_TP20R
TP_ON: HECTOR_WATCH_1_TPTP20R; HECTOR_WATCH_1_TP20R
TP_OP: HECTOR_WATCH_1_TPTP20R; HECTOR_WATCH_1_TP20R
TP_VBAT: HECTOR_WATCH_1_TPTP20R; HECTOR_WATCH_1_TP20R
U3: MAX17048G+T10; ESP32_C6_LIBRARY_SON50P200X200X80-9N

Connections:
3V3: C34.2, DMG2305UX-7.2 (S), IC2.C2 (VDD), R5.2, R7.2, R8.2, R_PWR_EPD.2; also elsewhere on the board
ALERT: U3.5 (!ALERT); also elsewhere on the board
D+: D3.4 (I/O2_2); also elsewhere on the board
D-: D3.6 (I/O1_2); also elsewhere on the board
DN: D3.1 (I/O1_1), J4.A7 (DN1), J4.B7 (DN2)
DP: D3.3 (I/O2_1), J4.A6 (DP1), J4.B6 (DP2)
EPD_3V3: 503480-2400.15, 503480-2400.16, C1-EP-DR.1, DMG2305UX-7.3 (D), EPD_C5.2, L5.2
EPD_BUSY: 503480-2400.9; also elsewhere on the board
EPD_CS: 503480-2400.12; also elsewhere on the board
EPD_DC: 503480-2400.11; also elsewhere on the board
EPD_RST: 503480-2400.10; also elsewhere on the board
GDR: 503480-2400.2, Q3.1 (G), R2_EP_DR.2
GND: 503480-2400.8, 503480-2400.17, 503480-2400.MP1, 503480-2400.MP2, C1-EP-DR.2, C27.1, C29.1, C30.1, C31.1, C32.1, C34.1, C42.1, C43.2, D3.2 (GND), D4.1 (K), EPD_C1.1, EPD_C2.1, EPD_C5.1, EPD_C6.1, EPD_C7.1, EPD_C8.1, EPD_C9.1, EPD_C10.1, EPD_C11.1, EPD_C12.1, IC2.B1 (IN/TRIG), IC2.B3 (GND), J4.A1_B12 (GND), J4.A12_B1 (GND), J4.SH1 (SHIELD), J4.SH2 (SHIELD), J4.SH3 (SHIELD), J4.SH4 (SHIELD), R1_USB.1, R2_EP_DR.1, R2_USB.2, R_TYPE_SEL.1, SJ1.1, SW_DN.1, SW_ENT.1, SW_UP.1, TP_BAT_GND.TP, U3.1 (CTG), U3.4 (GND), U3.6 (QSTRT), U3.9 (EP); also elsewhere on the board
HAPTIC_EN: IC2.A1 (EN); also elsewhere on the board
MOSI: 503480-2400.14; also elsewhere on the board
unnamed: C2-EP-DR.2, D5.2 (A), L5.1, Q3.3 (D)
unnamed: C2-EP-DR.1, D2.1 (K), D4.2 (A)
unnamed: R1_EP_DR.1, R_TYPE_SEL.2, SJ1.2
unnamed: 503480-2400.5, EPD_C1.2
unnamed: 503480-2400.4, EPD_C2.2
unnamed: 503480-2400.18, EPD_C6.2
unnamed: C32.2, IC2.A2 (REG)
unnamed: 503480-2400.19, EPD_C7.2
unnamed: 503480-2400.20, EPD_C8.2
unnamed: 503480-2400.22, EPD_C10.2
unnamed: 503480-2400.24, EPD_C12.2
unnamed: J4.A5 (CC1), R1_USB.2
unnamed: J4.B5 (CC2), R2_USB.1
OUT+: IC2.A3 (OUT+), TP_OP.TP
OUT-: IC2.C3 (OUT-), TP_ON.TP
P0.13: C30.2, R5.1, SW_UP.2; also elsewhere on the board
P0.14: C31.2, R8.1, SW_ENT.2; also elsewhere on the board
P1.01: DMG2305UX-7.1 (G), R_PWR_EPD.1; also elsewhere on the board
P1.02: C29.2, R7.1, SW_DN.2; also elsewhere on the board
PREVGH: 503480-2400.21, D5.1 (K), EPD_C9.2
PREVGL: 503480-2400.23, D2.2 (A), EPD_C11.2
RESE: 503480-2400.3, Q3.2 (S), R1_EP_DR.2
SCK: 503480-2400.13; also elsewhere on the board
SCL: IC2.C1 (SCL), U3.7 (SCL); also elsewhere on the board
SDA: IC2.B2 (SDA), U3.8 (SDA); also elsewhere on the board
VBAT: C27.2, TP_VBAT.TP, U3.2 (CELL), U3.3 (VDD); also elsewhere on the board
VBUS: C42.2, C43.1, D3.5 (VBUS), J4.A4_B9 (VBUS), J4.A9_B4 (VBUS); also elsewhere on the board

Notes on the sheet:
Haptic Driver
E-Paper Display Connector
E-Paper Drive Circuit
Buttons
Fuel Gauge
USB C Connector & ESD Protection

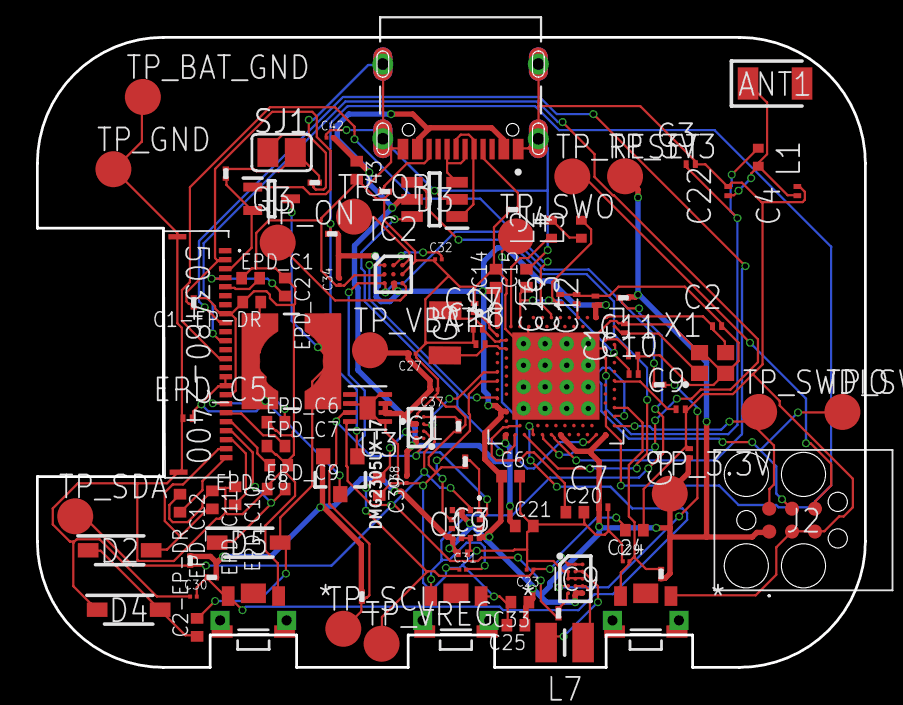
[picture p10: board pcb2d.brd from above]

Board: 2 copper layers, 46.0 x 35.0 mm, 105 parts (0 on the bottom side), 70 nets.

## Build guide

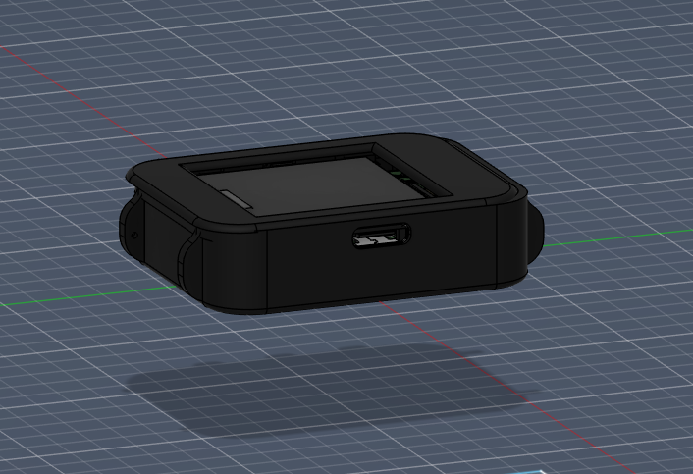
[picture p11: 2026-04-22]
Images/watchassembly.png

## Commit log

2026-04-22 Rename Captură de ecran 2026-04-22 234811.png to explodedview
2026-04-22 Rename Captură de ecran 2026-04-23 000929.png to watchassembly.png
2026-04-22 Enhance README with hardware details and BOM
    Updated the README.md file with detailed hardware descriptions, BOM, and pin usage for the nRF52840 microcontroller.

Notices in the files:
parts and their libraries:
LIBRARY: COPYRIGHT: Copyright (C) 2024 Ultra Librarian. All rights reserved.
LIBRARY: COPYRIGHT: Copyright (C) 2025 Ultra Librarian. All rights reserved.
